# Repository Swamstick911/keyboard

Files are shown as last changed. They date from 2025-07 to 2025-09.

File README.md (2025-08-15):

# Mechatron

## About

Mechatron is a 65% mechanical keyboard. It has some features listed below:
- An OLED Display [SSD1306]
- A Rotary Encoder [EC11]
- RGB Underglow
- Tactile Switches

---

## Firmware

The firmware will be KMK which will be written in micropython, as I am using a Raspberry Pi Pico, it makes this easier. Still working on the firmware of the keyboard, for updates check the JOURNAL.md file!

---

## Bill of Materials (BOM)

| Name | Quantity | Cost | Link |
|:---|:---|:---|:---|
| Gateron EF Grayish | 80 | $18.19 | https://neomacro.in/products/gateron-ef-grayish |
| Durock Smokey Screw-In Stabilizers V2 (4+1 w/ 6.25u spacebar) | 1 | $18.58 | https://stackskb.com/store/durock-smokey-screw-in-stabilizers-v2/ |
| Cherry Profile PBT Keycaps | 1 | $15.15 | https://stackskb.com/store/veekos-gradient-keycaps-cherry-profile-135-keys/ |
| Diode 1N4148 Through-Hole | 100 | $1.17  | https://www.amazon.in/dp/B084ZP5BJ3?ref_=cm_sw_r_cp_ud_dp_YPW3WFYTE31QA18570D1&_encoding=UTF8&psc=1 |
| WS2812B RGB LED | 8 | $2.76  | https://www.adafruit.com/product/1655 |
| Header 1x4 (I2C OLED) | 1 | $0.10  | https://www.digikey.in/en/products/detail/amphenol-fci/20021121-00010T4LF/10014539 |
| OLED | 1 | $1.92  | https://www.amazon.in/Robodo-Electronics-D1286464-Display-Arduino/dp/B07B92SFJV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 |
| Rotary Encoder EC11 w/ Push | 1 | $2.00  | https://www.adafruit.com/product/377 |
| I2C Expander (PCF8574) | 1 | $0.83  | https://www.digikey.in/en/products/detail/nxp-usa-inc/PCF8574T-3-518/735505 |
| M3 x 20mm Bolt | 15 | $1.73  | https://www.amazon.in/dp/B0CX99K2RL?ref_=cm_sw_r_cp_ud_dp_WPFQM677EMXT3KKH904P&_encoding=UTF8 |
| M3 Nuts | 8 | $1.16  | https://www.amazon.in/dp/B09J92WY5Q?ref_=cm_sw_r_cp_ud_dp_7TEKARN0PX76YMEZR3TW&_encoding=UTF8&psc=1 |
| M3 x 5mm Heatset Insert | 25 | $2.09  | https://www.amazon.in/dp/B0CX1BS7DJ?ref_=cm_sw_r_cp_ud_dp_13RMQGNJ1CXSNS92NXVW |
| PCB - (Black Color) | 5 | $69.99 | nan |
| Raspberry Pi Pico | 1 | $5.19  | https://www.amazon.in/Raspberry-Pi-Headers-Soldered-Micro/dp/B08WPNM7JB/ref=sr_1_2?sr=8-2 |
| Case - top | mid | bottom | 1 |
---

## Images:

















---

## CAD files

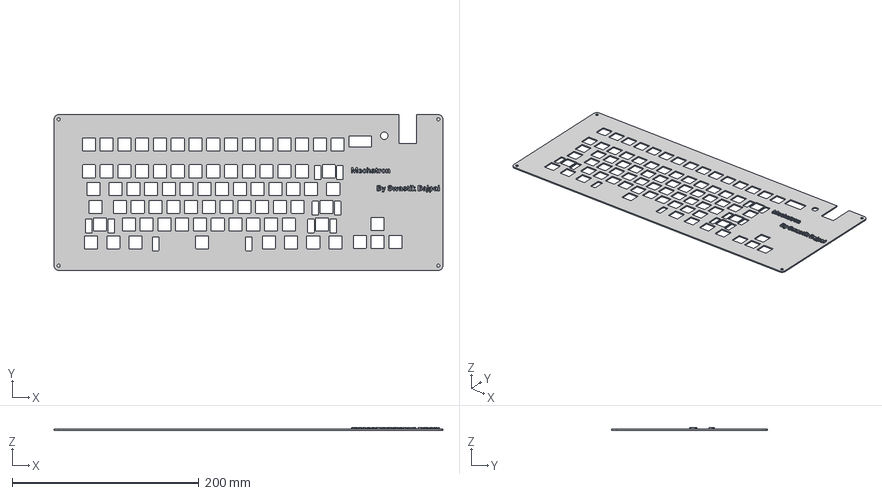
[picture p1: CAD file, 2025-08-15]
CAD/case top parts - case top.step
417.0 x 167.0 x 3.50 mm

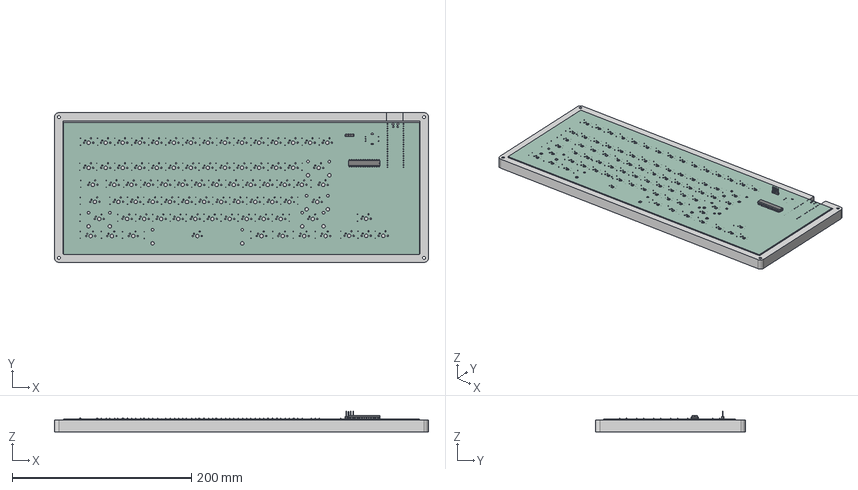
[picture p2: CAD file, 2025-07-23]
CAD/Keyboard case.step
417.0 x 167.0 x 23.0 mm

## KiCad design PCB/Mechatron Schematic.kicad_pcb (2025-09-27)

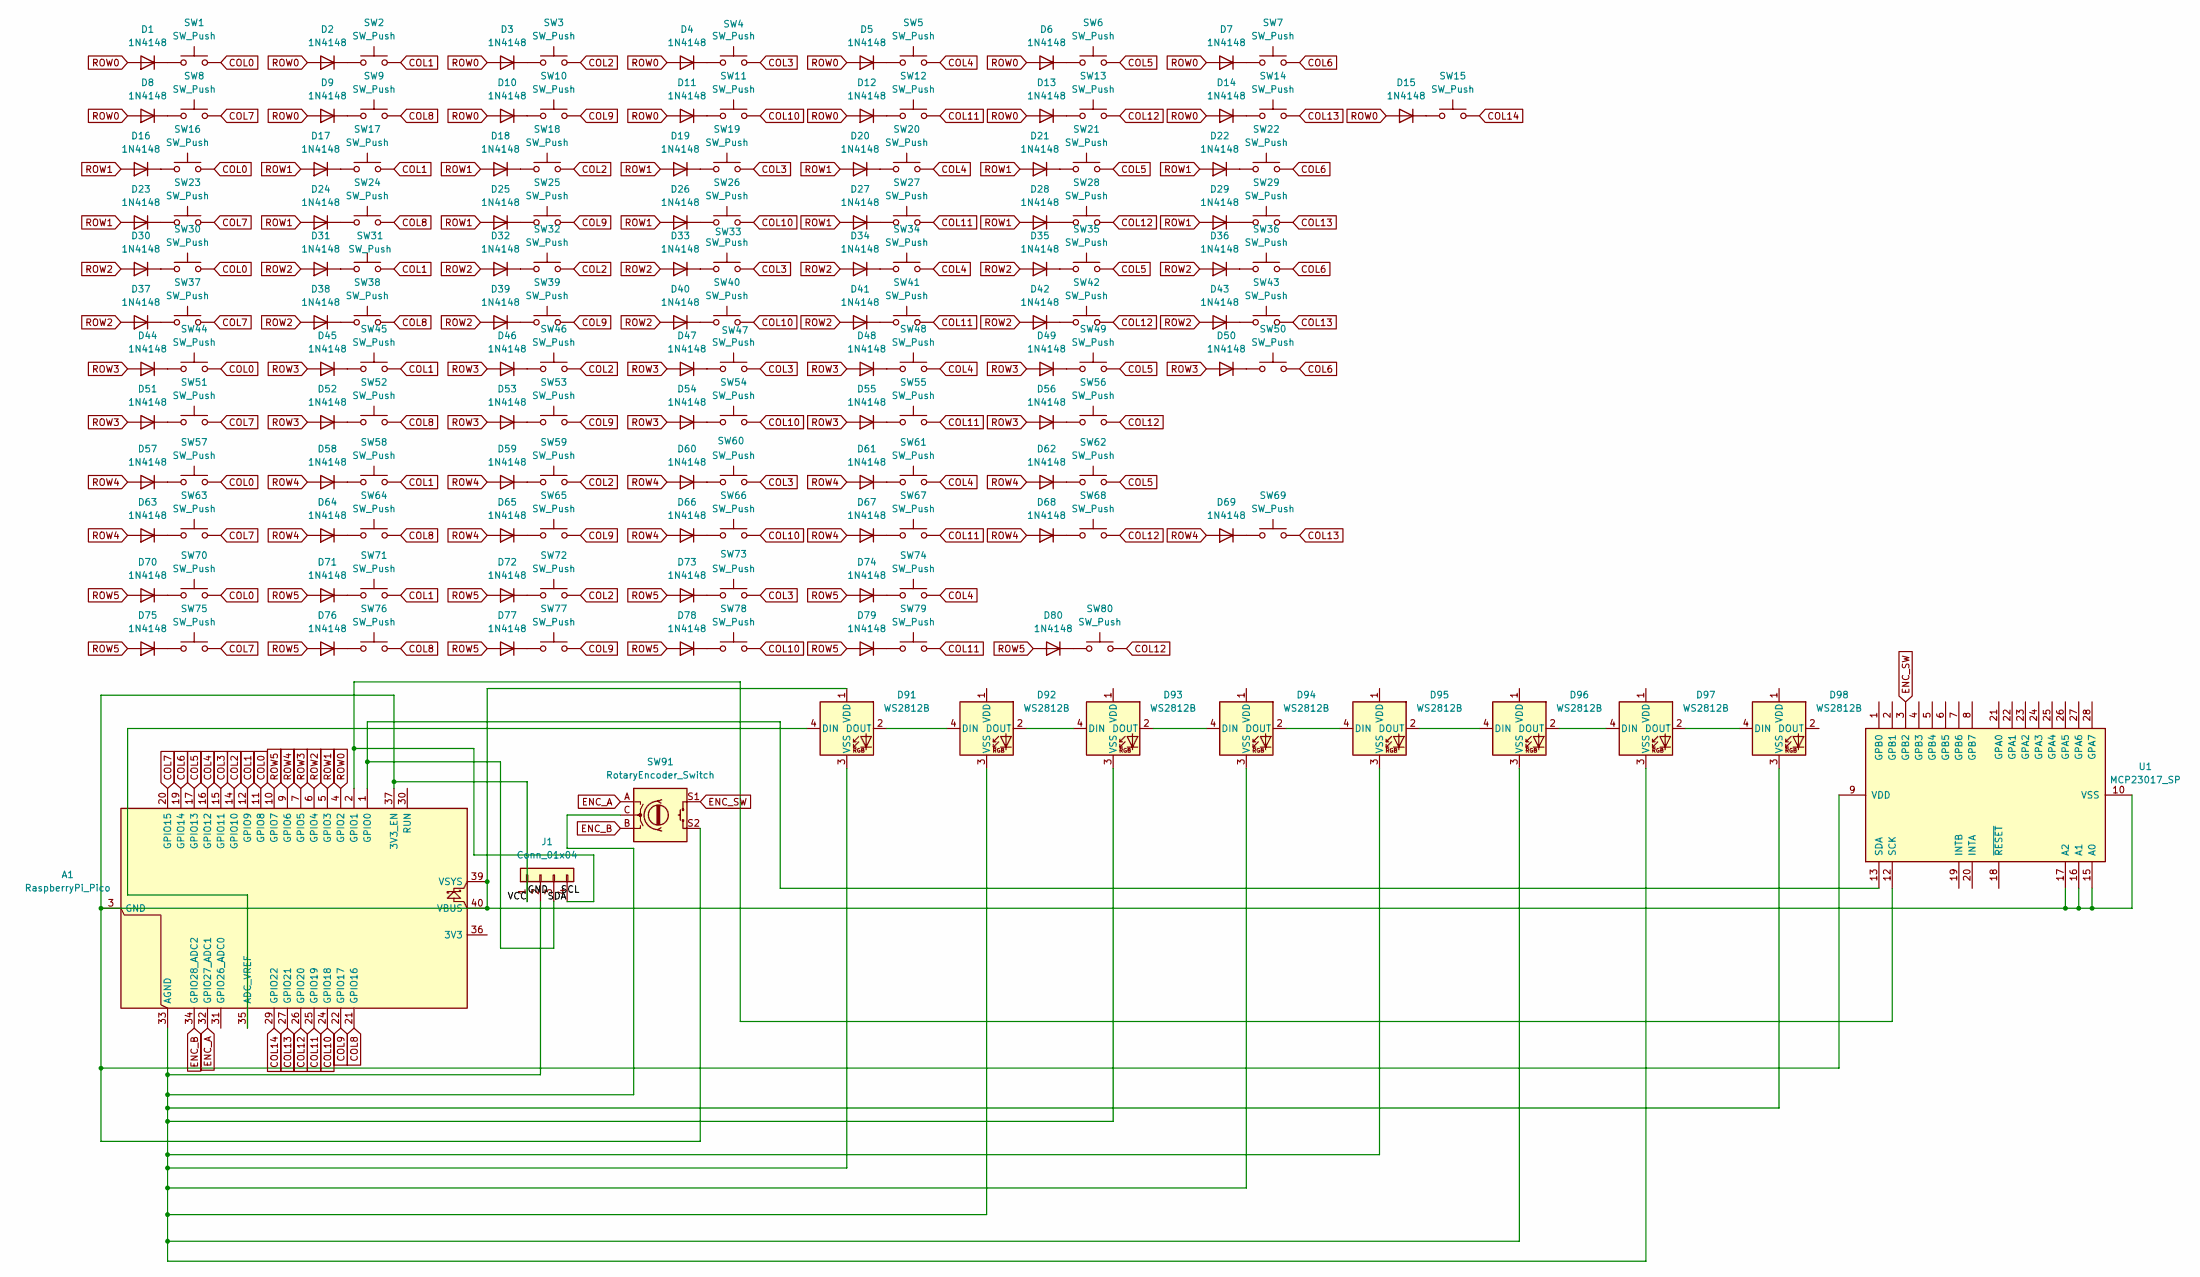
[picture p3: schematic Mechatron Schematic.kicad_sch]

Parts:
A1: RaspberryPi_Pico; RaspberryPi_Pico_Common_Unspecified
D1, D2, D3, D4, D5, D6, D7, D8, D9, D10, D11, D12, D13, D14, D15, D16, D17, D18, D19, D20, D21, D22, D23, D24, D25, D26, D27, D28, D29, D30, D31, D32, D33, D34, D35, D36, D37, D38, D39, D40, D41, D42, D43, D44, D45, D46, D47, D48, D49, D50, D51, D52, D53, D54, D55, D56, D57, D58, D59, D60, D61, D62, D63, D64, D65, D66, D67, D68, D69, D70, D71, D72, D73, D74, D75, D76, D77, D78, D79, D80: 1N4148; D_DO-35_SOD27_P7.62mm_Horizontal
D91, D92, D93, D94, D95, D96, D97, D98: WS2812B; LED_WS2812B_PLCC4_5.0x5.0mm_P3.2mm
J1: Conn_01x04; PinHeader_1x04_P2.54mm_Vertical
SW1, SW2, SW3, SW4, SW5, SW6, SW7, SW8, SW9, SW10, SW11, SW12, SW13, SW14, SW15, SW16, SW17, SW18, SW19, SW20, SW21, SW22, SW23, SW24, SW25, SW26, SW27, SW28, SW31, SW32, SW33, SW34, SW35, SW36, SW37, SW38, SW39, SW40, SW41, SW42, SW45, SW46, SW47, SW48, SW49, SW50, SW51, SW52, SW53, SW54, SW55, SW58, SW59, SW60, SW61, SW62, SW63, SW64, SW65, SW66, SW67, SW69, SW78, SW79, SW80: SW_Push; SW_Cherry_MX_1.00u_PCB
SW29: SW_Push; SW_Cherry_MX_2.00u_PCB
SW30, SW43: SW_Push; SW_Cherry_MX_1.50u_PCB
SW44: SW_Push; SW_Cherry_MX_1.75u_PCB
SW56, SW57: SW_Push; SW_Cherry_MX_2.25u_PCB
SW68: SW_Push; SW_Cherry_MX_2.75u_PCB
SW70, SW71, SW72, SW74, SW75, SW76, SW77: SW_Push; SW_Cherry_MX_1.25u_PCB
SW73: SW_Push; SW_Cherry_MX_6.25u_PCB
SW91: RotaryEncoder_Switch; RotaryEncoder_Alps_EC11E-Switch_Vertical_H20mm
U1: MCP23017_SP; DIP-28_W7.62mm

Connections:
/GND: A1.3 (GND), A1.8 (GND), A1.13 (GND), A1.18 (GND), A1.23 (GND), A1.28 (GND), A1.37 (3V3_EN), A1.38 (GND), A1.39 (VSYS), A1.40 (VBUS), D91.1 (VDD), J1.1, SW91.S2, U1.9 (VDD), U1.10 (VSS), U1.15 (A0), U1.16 (A1), U1.17 (A2)
COL0: A1.11 (GPIO8), SW1.2, SW16.2, SW30.2, SW44.2, SW57.2, SW70.2
COL1: A1.12 (GPIO9), SW2.2, SW17.2, SW31.2, SW45.2, SW58.2, SW71.2
COL2: A1.14 (GPIO10), SW3.2, SW18.2, SW32.2, SW46.2, SW59.2, SW72.2
COL3: A1.15 (GPIO11), SW4.2, SW19.2, SW33.2, SW47.2, SW60.2, SW73.2
COL4: A1.16 (GPIO12), SW5.2, SW20.2, SW34.2, SW48.2, SW61.2, SW74.2
COL5: A1.17 (GPIO13), SW6.2, SW21.2, SW35.2, SW49.2, SW62.2
COL6: A1.19 (GPIO14), SW7.2, SW22.2, SW36.2, SW50.2
COL7: A1.20 (GPIO15), SW8.2, SW23.2, SW37.2, SW51.2, SW63.2, SW75.2
COL8: A1.21 (GPIO16), SW9.2, SW24.2, SW38.2, SW52.2, SW64.2, SW76.2
COL9: A1.22 (GPIO17), SW10.2, SW25.2, SW39.2, SW53.2, SW65.2, SW77.2
COL10: A1.24 (GPIO18), SW11.2, SW26.2, SW40.2, SW54.2, SW66.2, SW78.2
COL11: A1.25 (GPIO19), SW12.2, SW27.2, SW41.2, SW55.2, SW67.2, SW79.2
COL12: A1.26 (GPIO20), SW13.2, SW28.2, SW42.2, SW56.2, SW68.2, SW80.2
COL13: A1.27 (GPIO21), SW14.2, SW29.2, SW43.2, SW69.2
COL14: A1.29 (GPIO22), SW15.2
ENC_A: A1.32 (GPIO27_ADC1), SW91.A
ENC_B: A1.34 (GPIO28_ADC2), SW91.B
ENC_SW: SW91.S1, U1.3 (GPB2)
unnamed: A1.35 (ADC_VREF), D91.4 (DIN)
unnamed: A1.33 (AGND), D91.3 (VSS), D92.3 (VSS), D93.3 (VSS), D94.3 (VSS), D95.3 (VSS), D96.3 (VSS), D97.3 (VSS), D98.3 (VSS), J1.2, SW91.C
unnamed: A1.1 (GPIO0), J1.3, U1.13 (SDA)
unnamed: A1.2 (GPIO1), J1.4, U1.12 (SCK)
unnamed: D1.1 (K), SW1.1
unnamed: D2.1 (K), SW2.1
unnamed: D3.1 (K), SW3.1
unnamed: D4.1 (K), SW4.1
unnamed: D5.1 (K), SW5.1
unnamed: D6.1 (K), SW6.1
unnamed: D7.1 (K), SW7.1
unnamed: D8.1 (K), SW8.1
unnamed: D9.1 (K), SW9.1
unnamed: D10.1 (K), SW10.1
unnamed: D11.1 (K), SW11.1
unnamed: D12.1 (K), SW12.1
unnamed: D13.1 (K), SW13.1
unnamed: D14.1 (K), SW14.1
unnamed: D15.1 (K), SW15.1
unnamed: D16.1 (K), SW16.1
unnamed: D17.1 (K), SW17.1
unnamed: D18.1 (K), SW18.1
unnamed: D19.1 (K), SW19.1
unnamed: D20.1 (K), SW20.1
unnamed: D21.1 (K), SW21.1
unnamed: D22.1 (K), SW22.1
unnamed: D23.1 (K), SW23.1
unnamed: D24.1 (K), SW24.1
unnamed: D25.1 (K), SW25.1
unnamed: D26.1 (K), SW26.1
unnamed: D27.1 (K), SW27.1
unnamed: D28.1 (K), SW28.1
unnamed: D29.1 (K), SW29.1
unnamed: D30.1 (K), SW30.1
unnamed: D31.1 (K), SW31.1
unnamed: D32.1 (K), SW32.1
unnamed: D33.1 (K), SW33.1
unnamed: D34.1 (K), SW34.1
unnamed: D35.1 (K), SW35.1
unnamed: D36.1 (K), SW36.1
unnamed: D37.1 (K), SW37.1
unnamed: D38.1 (K), SW38.1
unnamed: D39.1 (K), SW39.1
unnamed: D40.1 (K), SW40.1
unnamed: D41.1 (K), SW41.1
unnamed: D42.1 (K), SW42.1
unnamed: D43.1 (K), SW43.1
unnamed: D44.1 (K), SW44.1
unnamed: D45.1 (K), SW45.1
unnamed: D46.1 (K), SW46.1
unnamed: D47.1 (K), SW47.1
unnamed: D48.1 (K), SW48.1
unnamed: D49.1 (K), SW49.1
unnamed: D50.1 (K), SW50.1
unnamed: D51.1 (K), SW51.1
unnamed: D52.1 (K), SW52.1
unnamed: D53.1 (K), SW53.1
unnamed: D54.1 (K), SW54.1
unnamed: D55.1 (K), SW55.1
unnamed: D56.1 (K), SW56.1
unnamed: D57.1 (K), SW57.1
unnamed: D58.1 (K), SW58.1
unnamed: D59.1 (K), SW59.1
unnamed: D60.1 (K), SW60.1
unnamed: D61.1 (K), SW61.1
unnamed: D62.1 (K), SW62.1
unnamed: D63.1 (K), SW63.1
unnamed: D64.1 (K), SW64.1
unnamed: D65.1 (K), SW65.1
unnamed: D66.1 (K), SW66.1
unnamed: D67.1 (K), SW67.1
unnamed: D68.1 (K), SW68.1
unnamed: D69.1 (K), SW69.1
unnamed: D70.1 (K), SW70.1
unnamed: D71.1 (K), SW71.1
unnamed: D72.1 (K), SW72.1
unnamed: D73.1 (K), SW73.1
unnamed: D74.1 (K), SW74.1
unnamed: D75.1 (K), SW75.1
unnamed: D76.1 (K), SW76.1
unnamed: D77.1 (K), SW77.1
unnamed: D78.1 (K), SW78.1
unnamed: D79.1 (K), SW79.1
unnamed: D80.1 (K), SW80.1
unnamed: D91.2 (DOUT), D92.4 (DIN)
unnamed: D92.2 (DOUT), D93.4 (DIN)
unnamed: D93.2 (DOUT), D94.4 (DIN)
unnamed: D94.2 (DOUT), D95.4 (DIN)
unnamed: D95.2 (DOUT), D96.4 (DIN)
unnamed: D96.2 (DOUT), D97.4 (DIN)
unnamed: D97.2 (DOUT), D98.4 (DIN)
ROW0: A1.4 (GPIO2), D1.2 (A), D2.2 (A), D3.2 (A), D4.2 (A), D5.2 (A), D6.2 (A), D7.2 (A), D8.2 (A), D9.2 (A), D10.2 (A), D11.2 (A), D12.2 (A), D13.2 (A), D14.2 (A), D15.2 (A)
ROW1: A1.5 (GPIO3), D16.2 (A), D17.2 (A), D18.2 (A), D19.2 (A), D20.2 (A), D21.2 (A), D22.2 (A), D23.2 (A), D24.2 (A), D25.2 (A), D26.2 (A), D27.2 (A), D28.2 (A), D29.2 (A)
ROW2: A1.6 (GPIO4), D30.2 (A), D31.2 (A), D32.2 (A), D33.2 (A), D34.2 (A), D35.2 (A), D36.2 (A), D37.2 (A), D38.2 (A), D39.2 (A), D40.2 (A), D41.2 (A), D42.2 (A), D43.2 (A)
ROW3: A1.7 (GPIO5), D44.2 (A), D45.2 (A), D46.2 (A), D47.2 (A), D48.2 (A), D49.2 (A), D50.2 (A), D51.2 (A), D52.2 (A), D53.2 (A), D54.2 (A), D55.2 (A), D56.2 (A)
ROW4: A1.9 (GPIO6), D57.2 (A), D58.2 (A), D59.2 (A), D60.2 (A), D61.2 (A), D62.2 (A), D63.2 (A), D64.2 (A), D65.2 (A), D66.2 (A), D67.2 (A), D68.2 (A), D69.2 (A)
ROW5: A1.10 (GPIO7), D70.2 (A), D71.2 (A), D72.2 (A), D73.2 (A), D74.2 (A), D75.2 (A), D76.2 (A), D77.2 (A), D78.2 (A), D79.2 (A), D80.2 (A)

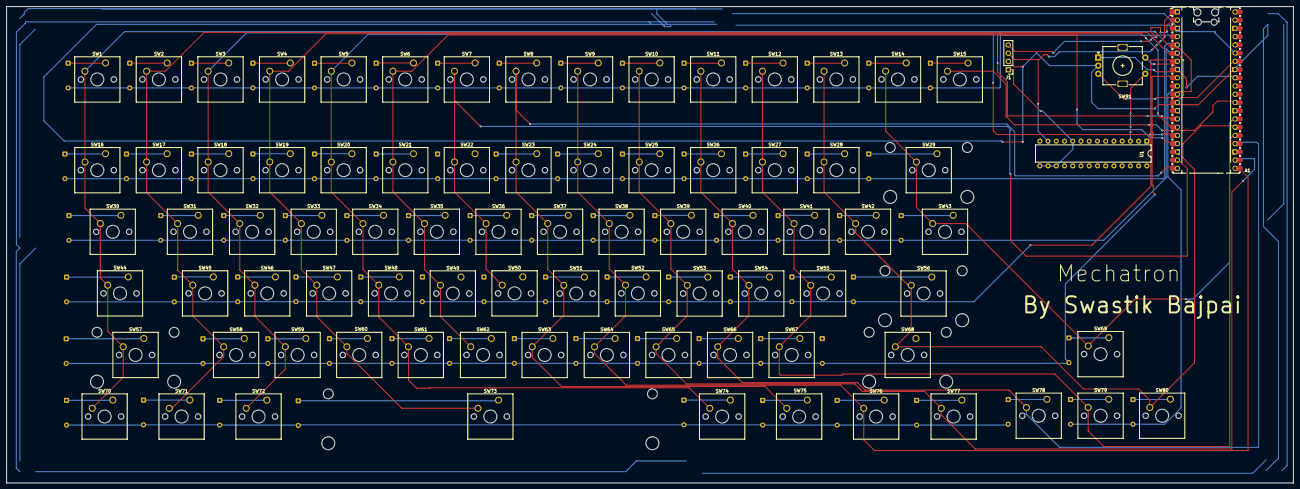
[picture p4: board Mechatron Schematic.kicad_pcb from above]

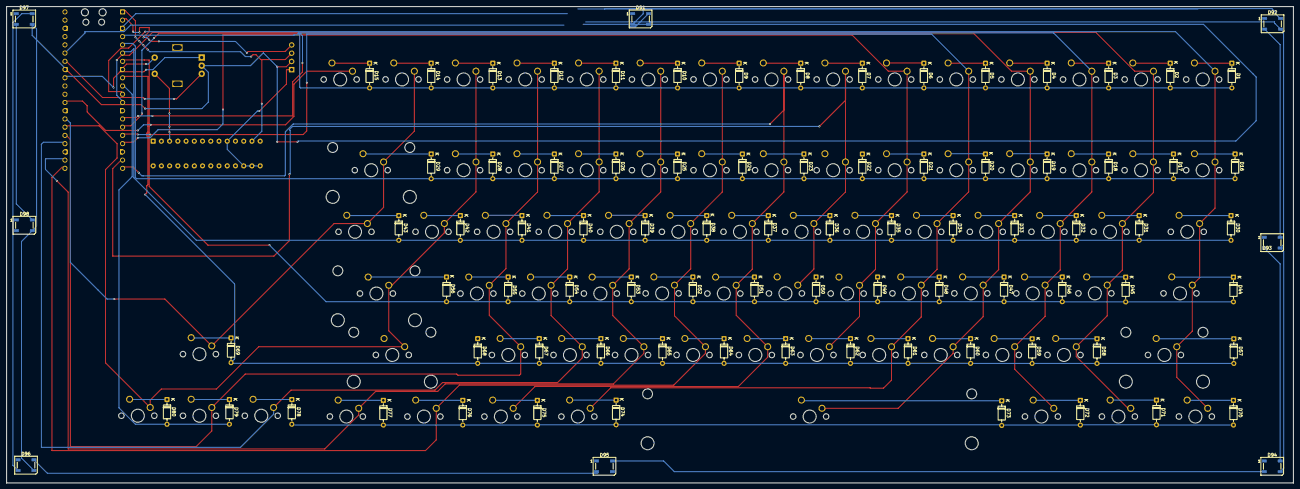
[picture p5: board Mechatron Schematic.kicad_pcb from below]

Board: 2 copper layers, 397.0 x 147.0 mm, 172 parts (88 on the bottom side), 116 nets.

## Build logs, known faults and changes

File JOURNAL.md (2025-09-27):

---
title: Mechatron
author: Swastik Bajpai
description: the project is a mechanical DIY keyboard with extra features (always a dream of making one)
created_at: 2025-06-08
---
## Total Time - 16-17 hours

## June 9th, 2025: (1 hour)
I made the basic design of the keyboard on www.keyboard-layout-editor.com
Keyboard Layout

## June 10th, 2025: (1 hour)
Today made the matrix of the keyboard and the firmware, some part is still left, here is a screenshot of the code
Code and matrix

## June 16th, 2025: (1 hour)
Today I made the basic schematic of the keyboard in KiCAD I will add the rest of the components later
Schematic

## June 18th, 2025: (2 hour)
Today I completed the schematic and will work on the PCB tomorrow
Full Schematic

## June 23rd, 2025: (1.5 hour)
Solved the issue of footprints of keys not showing, this is the pcb atm, will place it and work it out soon!
PCB

## June 25th, 2025: (1.5 hour)
PCB almost done only the routing part is left
PCB2

## June 26th, 2025: (2 hour)
Organised the board a bit and did the routing but it was wrong, so I am redoing it
PCB3

## June 28th, 2025: (1.5 hour)
Asked my friends to look at my PCB, they told me the issues so now I am fixing them, I am like halfway there. I reorganised the keys and the diodes as the keys need to be closer, so here's the latest pic I have 

PCB4

## June 29th, 2025: (2 hour)
Finally completed the PCB today without any errors!! Thanks to everyone who helped

PCB5
3Dview_1
3Dview_2

## July 23rd, 2025: (2.5 hour)
Yes I know I am journaling after a long time that is because I was busy between these days today I tried to complete the case and this is how it turned out. Though I forgot to add space for the display and encoder. I followed the hackpad case tutorial



## August 15th, 2025 (1 hour)
Added some complexity to the case as per the review, added text which said the name of the project



## September 27th, 2025 (30 minutes)
Changed the position of the header a bit as it was not suitable with the display I will use



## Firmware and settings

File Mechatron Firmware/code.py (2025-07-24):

from kmk.kmk_keyboard import KMKKeyboard
from kmk.scanners import DiodeOrientation
from kmk.modules.layers import Layers
from kmk.keys import KC

import keymap

keyboard = KMKKeyboard()
keyboard.modules.append(Layers())

# GPIO pin setup
keyboard.row_pins = (GP2, GP3, GP4, GP5, GP6, GP7)
keyboard.col_pins = (GP8, GP9, GP10, GP9, GP10, GP11, GP12, GP13, GP14, GP15, GP16, GP17, GP18, GP19, GP20, GP21, GP22)
keyboard.diode_orientation = DiodeOrientation.COL2ROW

keyboard.keymap = keymap.keymap

if __name__ == '__main__':
    keyboard.go()

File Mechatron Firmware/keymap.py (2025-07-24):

from kmk.keys import KC

keymap = [
    [KC.ESC, KC.F1, KC.F2, KC.F3, KC.F4, KC.F5, KC.F6, KC.F7, KC.F8, KC.F9, KC.F10, KC.F11, KC.F12, KC.PSCREEN, KC.DEL],
    [KC.GRAVE, KC._1, KC._2, KC._3, KC._4, KC._5, KC._6, KC._7, KC._8, KC._9, KC._0, KC.MINS, KC.EQL, KC.BSPC],
    [KC.TAB, KC.Q, KC.W, KC.E, KC.R, KC.T, KC.Y, KC.U, KC.I, KC.O, KC.P, KC.LBRC, KC.RBRC, KC.BSLS],
    [KC.CAPS, KC.A, KC.S, KC.D, KC.F, KC.G, KC.H, KC.J, KC.K, KC.L, KC.SCLN, KC.QUOT, KC.ENTER],
    [KC.LSFT, KC.Z, KC.X, KC.C, KC.V, KC.B, KC.N, KC.M, KC.COMM, KC.DOT, KC.SLSH, KC.RSFT, KC.UP],
    [KC.LCTL, KC.LGUI, KC.LALT, KC.SPC, KC.RALT, KC.NO, KC.RCTL, KC.APP, KC.LEFT, KC.DOWN, KC.RIGHT],
]

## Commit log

2025-06-19 Adding the completed schematic
    [Mechatron Schematic.kicad_sch]
2025-06-29 Deleting old schematic file
    [Mechatron Schematic.kicad_sch]
2025-06-29 Adding the new schematic file
2025-06-29 Adding Gerber files
    [Mechatron Schematic-B_Cu.gbr, Mechatron Schematic-B_Mask.gbr, Mechatron Schematic-B_Paste.gbr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]
2025-07-23 Adding the CAD files
    [Keyboard case.step, case top.step]
2025-07-23 Adding the BOM file
    [Mechatron_BOM.csv]
2025-08-02 Removing old CAD files
    [case top.step]
2025-08-04 Adding PCB files
2025-08-04 Adding BOM to README.md
2025-08-04 Adding the files which were left
    [Mechatron Schematic.kicad_pcb, Mechatron Schematic.kicad_sch]
2025-08-04 Deleting schematic pdf
2025-08-04 Rename Mechatron Schematic.zip to Gerber.zip
2025-08-15 Deleting old CAD case top file
    [case top.step]
2025-08-15 Adding new case top file
    [case top parts - case top.step]
2025-09-27 Adding the changed PCB file
    [Mechatron Schematic.kicad_pcb]
2025-09-27 Adding the new gerber file
2025-09-27 Deleting old gerber file
